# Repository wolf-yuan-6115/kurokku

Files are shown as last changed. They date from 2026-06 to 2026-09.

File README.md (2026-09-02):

# Kurokku

Kurokku is an ESP32 based Wi-Fi smart clock. Featuring E-ink display, it can pull weather data, calendar and display realtime clock. It is designed to be a simple and elegant clock that can be placed on a desk. There's also a SHT40 temperature and humidity sensor to provide more information.

Case was not designed and it's intended to just directly use screw as stand.

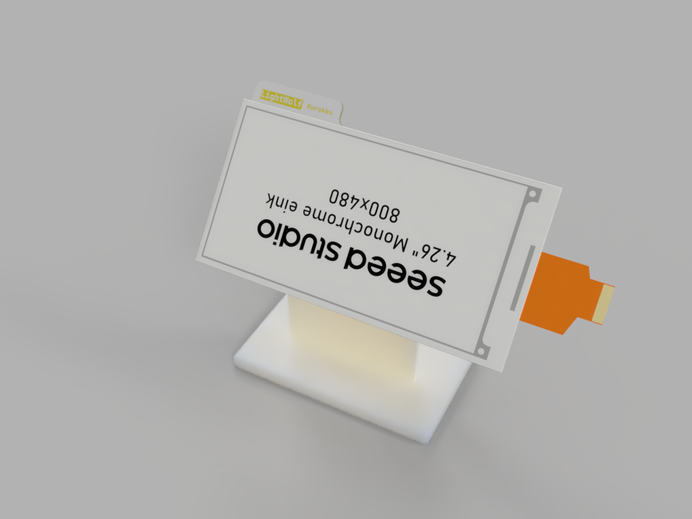
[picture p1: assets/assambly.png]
Assamble


> [!NOTE]
> Please don't expect me to find a 3D model for e-ink display and include it.

Driver

front

> Note that display is not here yet because it's going to order seperately.

## Schematic

schematic

## Routing

routing

## BOM

| Name | Qty | Total (USD) | Distributor |
| --- | --- | --- | --- |
| [Waveshare e-ink display](https://detail.tmall.com/item.htm?id=763853854896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) | 1 | 19.50 | Taobao |
| [Seeed Xiao ESP32-S3](https://item.taobao.com/item.htm?id=717378181472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) | 1 | 8.20 | Taobao |
| PCB & PCBA | 1 | 28.96 | JLCPCB |
| Shipping | 1 | 0.5 | Taobao |
| Total | - | 57.16 | - |

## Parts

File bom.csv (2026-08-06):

Name | Purpose | Quantity | Total Cost (USD) | Link | Distributor
Waveshare e-ink display | For displaying things. (4.26 inch B/W) | 1 | 19.50 | https://detail.tmall.com/item.htm?from=cart&id=763853854896&skuId=5256424296363&upStreamPrice=13068 | Taobao
Seeed Xiao ESP32-S3 | To drive the display & connect to web | 1 | 8.20 | https://item.taobao.com/item.htm?from=cart&id=717378181472&upStreamPrice=5500 | Taobao
PCB & PCBA | Make board (not sure why JLC have 20 dollar coupon now) | 1 | 28.96 |  | JLCPCB

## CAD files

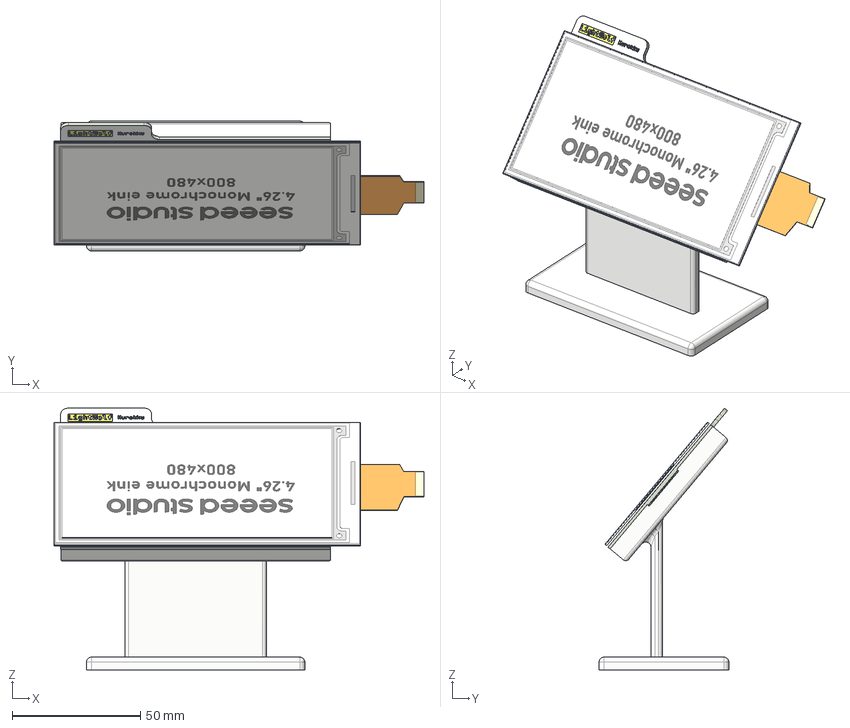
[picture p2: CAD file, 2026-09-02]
assembly.step
144.5 x 50.7 x 102.2 mm
R_0603_1608Metric x 6
C_0603_1608Metric x 13
D_SOD-123_3 x 3
L_1008_2520Metric_1
WSOF-6_L1.6-W2.6-H0.8-P0.50_2 x 2
BOSS-EXTRUDE14_8_
BOSS-EXTRUDE7_4_
BOSS-EXTRUDE7_3_
BOSS-EXTRUDE14_4_
BOSS-EXTRUDE14_2_
BOSS-EXTRUDE14_11_
BOSS-EXTRUDE7_7_
BOSS-EXTRUDE14_9_
BOSS-EXTRUDE14_3_
BOSS-EXTRUDE14_7_
MIRROR2
BOSS-EXTRUDE14_5_
BOSS-EXTRUDE14_12_
BOSS-EXTRUDE7_8_
BOSS-EXTRUDE7_1_
BOSS-EXTRUDE14_10_
BOSS-EXTRUDE7_9_
BOSS-EXTRUDE14_6_
BOSS-EXTRUDE14_1_
BOSS-EXTRUDE7_6_
BOSS-EXTRUDE7_2_
CUT-EXTRUDE5
BOSS-EXTRUDE7_5_
Shield
Pins x 2
U.FL-R-SMT-1_10_ v1
DFN-4_L1.5-W1.5-P0.8_1
FPC-SMD_L17.6-W5.4-H2.0-AFC07-S24FCC-00_1
SOT_23
kanji_copper
kanji_via
kanji_silkscreen
kanji_silkscreen_1
kanji_soldermask
kanji_soldermask_1
kanji_PCB

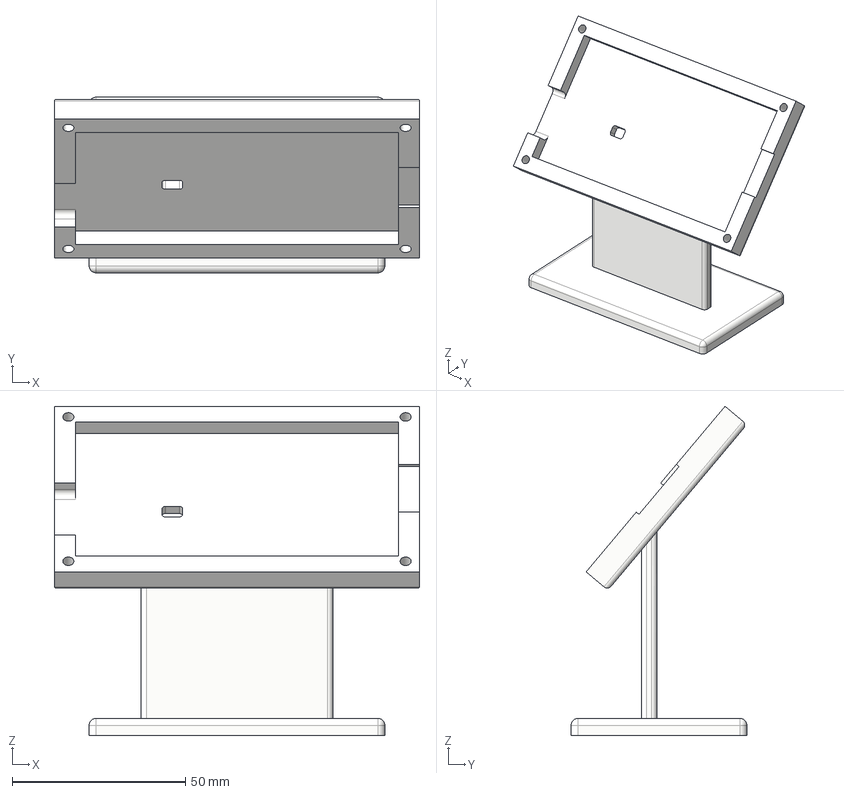
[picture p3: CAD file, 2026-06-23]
case/Kurokku case.step
105.3 x 50.7 x 95.0 mm

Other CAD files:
case/Kurokku case.f3d

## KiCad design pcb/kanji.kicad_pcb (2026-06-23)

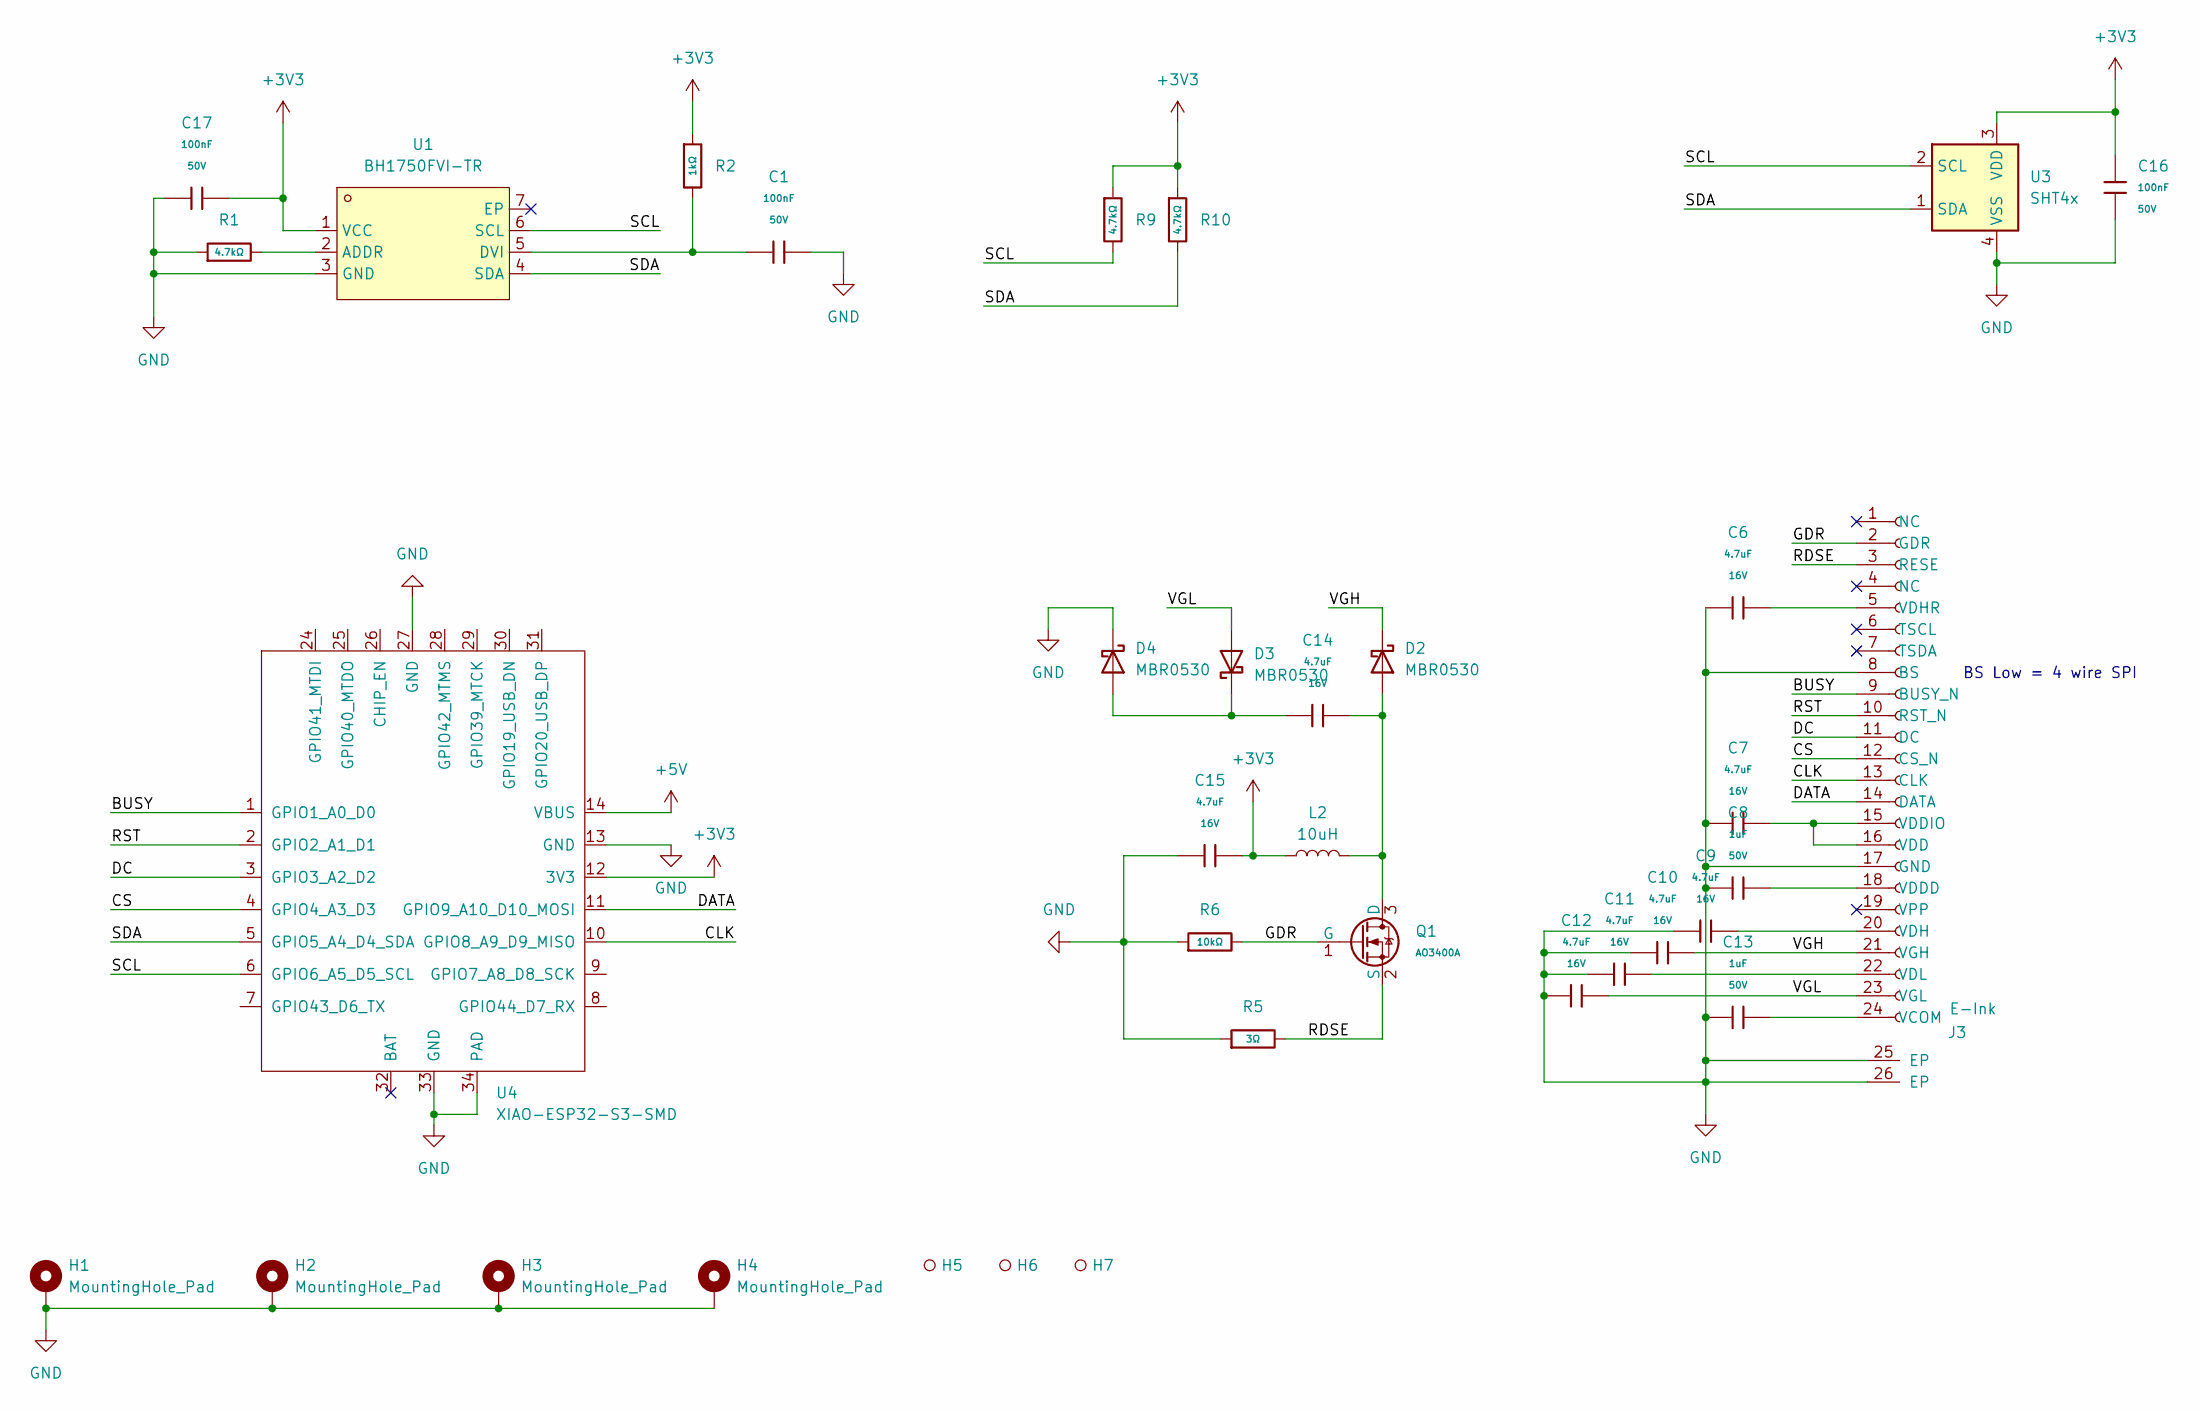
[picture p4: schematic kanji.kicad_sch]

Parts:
C1, C16, C17: 100nF; C_0603; Voltage Rated 50V; Tolerance ±10%; Part CC0603KRX7R9BB104; LCSC C14663
C6, C7, C9, C10, C11, C12, C14, C15: 4.7uF; C_0603; Voltage Rated 16V; Tolerance ±10%; Part CL10A475KO8NNNC; LCSC C19666
C8, C13: 1uF; C_0603; Voltage Rated 50V; Tolerance ±10%; Part CL10A105KB8NNNC; LCSC C15849
D2, D3, D4: MBR0530; D_SOD-123
H1, H2, H3, H4: MountingHole_Pad; MountingHole_3.2mm_M3_Pad_Via
H5, H6, H7: Hole_Tooling_JLCPCB
J3: E-Ink; FPC-SMD_AFC07-S24FCC-00
L2: 10uH; L_1008_2520Metric; LCSC C2049757
Q1: AO3400A; Q_SOT-23; Part AO3400A; LCSC C20917
R1, R9, R10: 4.7kΩ; R_0603; Overload Voltage (Max) 75V; Tolerance ±1%; Part 0603WAF4701T5E; LCSC C23162
R2: 1kΩ; R_0603; Overload Voltage (Max) 75V; Tolerance ±1%; Part 0603WAF1001T5E; LCSC C21190
R5: 3Ω; R_0603; Overload Voltage (Max) 75V; Tolerance ±1%; Part 0603WAF220KT5E; LCSC C23157
R6: 10kΩ; R_0603; Overload Voltage (Max) 75V; Tolerance ±1%; Part 0603WAF1002T5E; LCSC C25804
U1: BH1750FVI-TR; WSOF-6_L2.6-W1.6-P0.50-TL-EP; MPN BH1750FVI-TR; LCSC Part C78960
U3: SHT4x; Sensirion_DFN-4_1.5x1.5mm_P0.8mm_SHT4x_NoCentralPad; LCSC C2909890
U4: XIAO-ESP32-S3-SMD

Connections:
+3V3: C15.2, C16.1, C17.2, L2.1, R2.1, R9.1, R10.1, U1.1 (VCC), U3.3 (VDD), U4.12 (3V3)
+5V: U4.14 (VBUS)
/BUSY: J3.9 (BUSY_N), U4.1 (GPIO1_A0_D0)
/CLK: J3.13 (CLK), U4.10 (GPIO8_A9_D9_MISO)
/CS: J3.12 (CS_N), U4.4 (GPIO4_A3_D3)
/DATA: J3.14 (DATA), U4.11 (GPIO9_A10_D10_MOSI)
/DC: J3.11 (DC), U4.3 (GPIO3_A2_D2)
/GDR: J3.2 (GDR), Q1.1 (G), R6.2
/RDSE: J3.3 (RESE), Q1.2 (S), R5.2
/RST: J3.10 (RST_N), U4.2 (GPIO2_A1_D1)
/SCL: R9.2, U1.6 (SCL), U3.2 (SCL), U4.6 (GPIO6_A5_D5_SCL)
/SDA: R10.2, U1.4 (SDA), U3.1 (SDA), U4.5 (GPIO5_A4_D4_SDA)
/VGH: C10.2, D2.1 (K), J3.21 (VGH)
/VGL: C12.2, D3.2 (A), J3.23 (VGL)
GND: C1.2, C6.1, C7.1, C8.1, C9.1, C10.1, C11.1, C12.1, C13.1, C15.1, C16.2, C17.1, D4.1 (K), H1.1 (1_1), H2.1 (1_1), H3.1 (1_1), H4.1 (1_1), J3.8 (BS), J3.17 (GND), J3.25 (EP), J3.26 (EP), R1.1, R5.1, R6.1, U1.3 (GND), U3.4 (VSS), U4.13 (GND), U4.27 (GND), U4.33 (GND), U4.34 (PAD)
unnamed: C14.2, D2.2 (A), L2.2, Q1.3 (D)
unnamed: C14.1, D3.1 (K), D4.2 (A)
unnamed: C13.2, J3.24 (VCOM)
unnamed: C7.2, J3.15 (VDDIO), J3.16 (VDD)
unnamed: C8.2, J3.18 (VDDD)
unnamed: C9.2, J3.20 (VDH)
unnamed: C6.2, J3.5 (VDHR)
unnamed: C11.2, J3.22 (VDL)
unnamed: R1.2, U1.2 (ADDR)
unnamed: C1.1, R2.2, U1.5 (DVI)

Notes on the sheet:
BS Low = 4 wire SPI

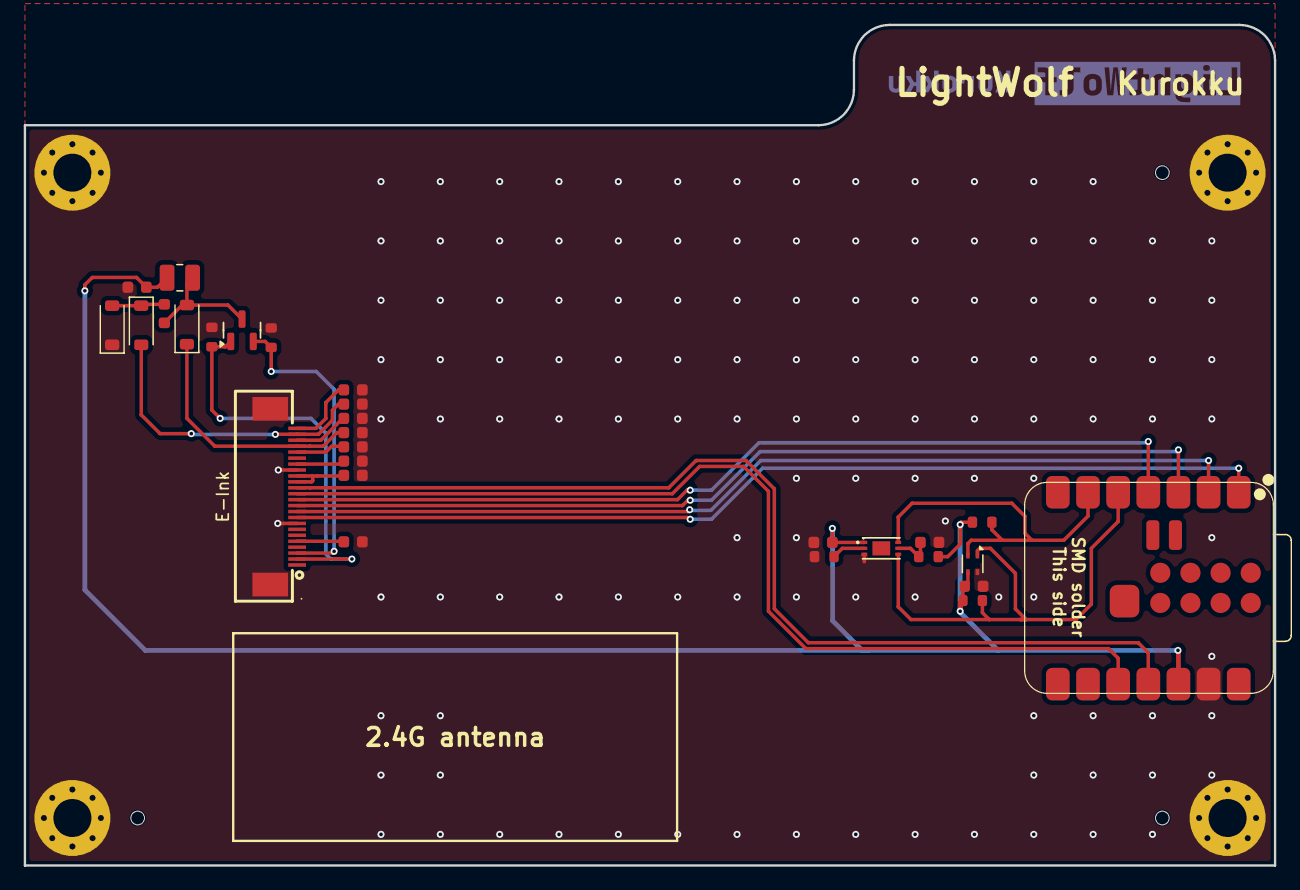
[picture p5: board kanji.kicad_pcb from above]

Board: 2 copper layers, 105.3 x 70.8 mm, 35 parts (0 on the bottom side), 24 nets.

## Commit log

2026-06-23 feat: add case and update readme
    [Kurokku case.f3d, Kurokku case.step, kanji.kicad_pcb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]
2026-08-06 feat: update project files
    [bom.csv, kanji.kicad_pcb, kanji.kicad_sch]
2026-09-02 fix: add display mounting assembly
    [assembly.step]
